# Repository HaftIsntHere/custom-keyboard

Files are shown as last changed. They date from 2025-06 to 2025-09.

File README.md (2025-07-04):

# Custom Keyboard
This is my fully custom keyboard, fitted with a 75% layout, 2 macro keys, a knob and an oled screen!

I made this project as a continuation for the hackpad, and I really wanted to know how building a real keyboard is, not just a macropad. This helped me finally understand how keyboards really work!
 <br>


## BOM

|Item |Quantity  |Price |Link # |
|---|---|---|---|
|INDIVIDUAL ITEMS | | | |
| | | | |
|Womier Coffee Cat keycaps |1 |26.54 USD |https://womierkeyboard.com/products/womier-coffee-cat-143?variant=40539585740871|
|Akko V3 Creamy Purple Pro switches |90 |33.72 USD |https://en.akkogear.com/product/akko-v3-creamy-purple-pro-switch |
|PCB |5 |13 + ~15 = 28 USD (can't see shipping estimate right now, it doesnt let me cause of war)| |
| | | | |
|ALIEXPRESS ITEMS | | | |
| | | | |
|Knob |1 |3.58 USD |https://www.aliexpress.com/item/1005007576522714.html |
|OLED Screen 128x32 |1 |3.68 USD |https://www.aliexpress.com/item/1005007038294972.html |
|DO-35 Diodes |100 |1.65 USD |https://www.aliexpress.com/item/4000142272546.html |
|Hot swap sockets |110 |15.59 USD |https://www.aliexpress.com/item/1005007476614771.html |
|Stabilizers (4x 2u + 1x 6.25u) |4+1 |7.24 USD |https://www.aliexpress.com/item/1005006528731543.html |
|ESP32 S3 Devkit C1 |1 |19.56 USD (including shipping) |https://www.aliexpress.com/item/1005003979778978.html |
|EC11 Rotary Encoder |1 |1.56 USD (including shipping) |https://www.aliexpress.com/item/1975155185.html |
|M3 Screws |20 |2.54 USD |https://www.aliexpress.com/item/32810872544.html |
|Poron strips |64 |4.75 USD |https://www.aliexpress.com/item/1005003607093794.html |
| | | | |
|AliExpress Total (including their discounts and stuff)| 51.33 USD| | |
| | | | |
|TOTAL | |139.59 USD | |

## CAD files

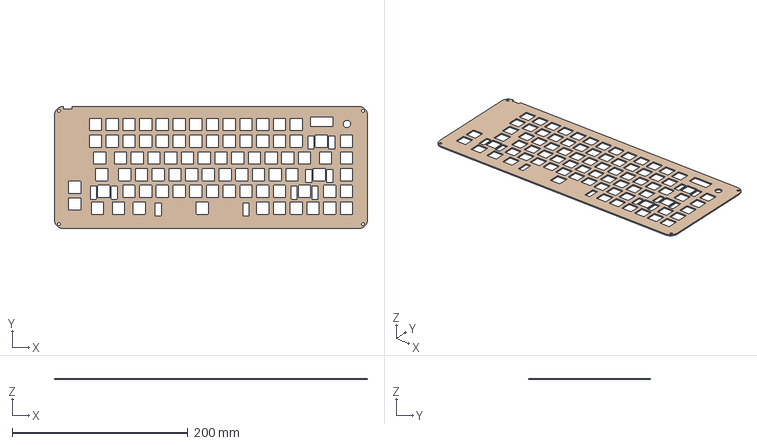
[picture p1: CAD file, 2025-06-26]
CAD/Top.step
356.4 x 139.1 x 1.50 mm

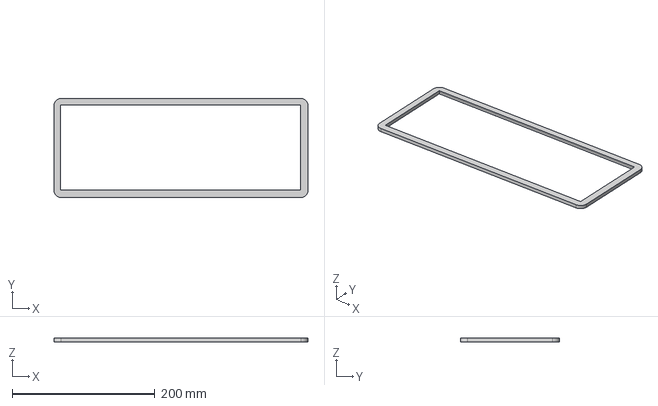
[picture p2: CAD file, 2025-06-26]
CAD/Top frame.step
356.5 x 139.0 x 5.00 mm

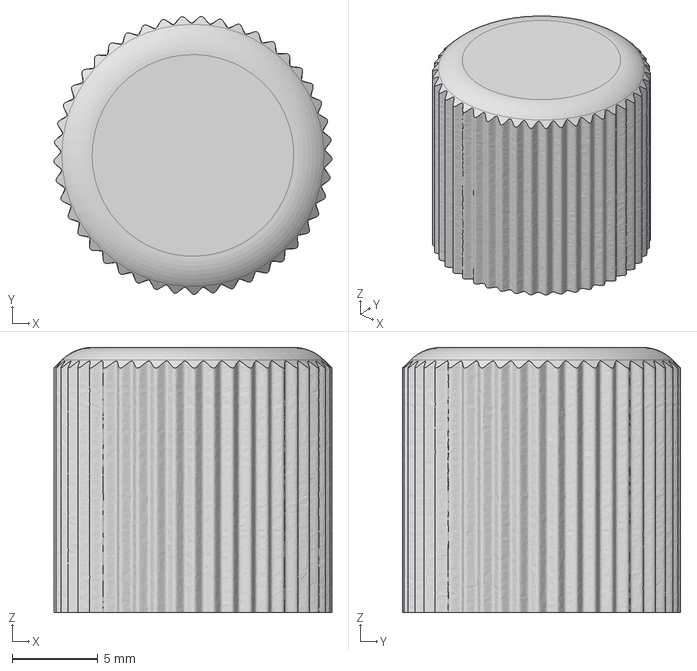
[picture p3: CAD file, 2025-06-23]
CAD/knob.step
16.3 x 16.2 x 15.5 mm

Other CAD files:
production/Bottom.step
CAD/Bottom.step
production/Knob cover.step

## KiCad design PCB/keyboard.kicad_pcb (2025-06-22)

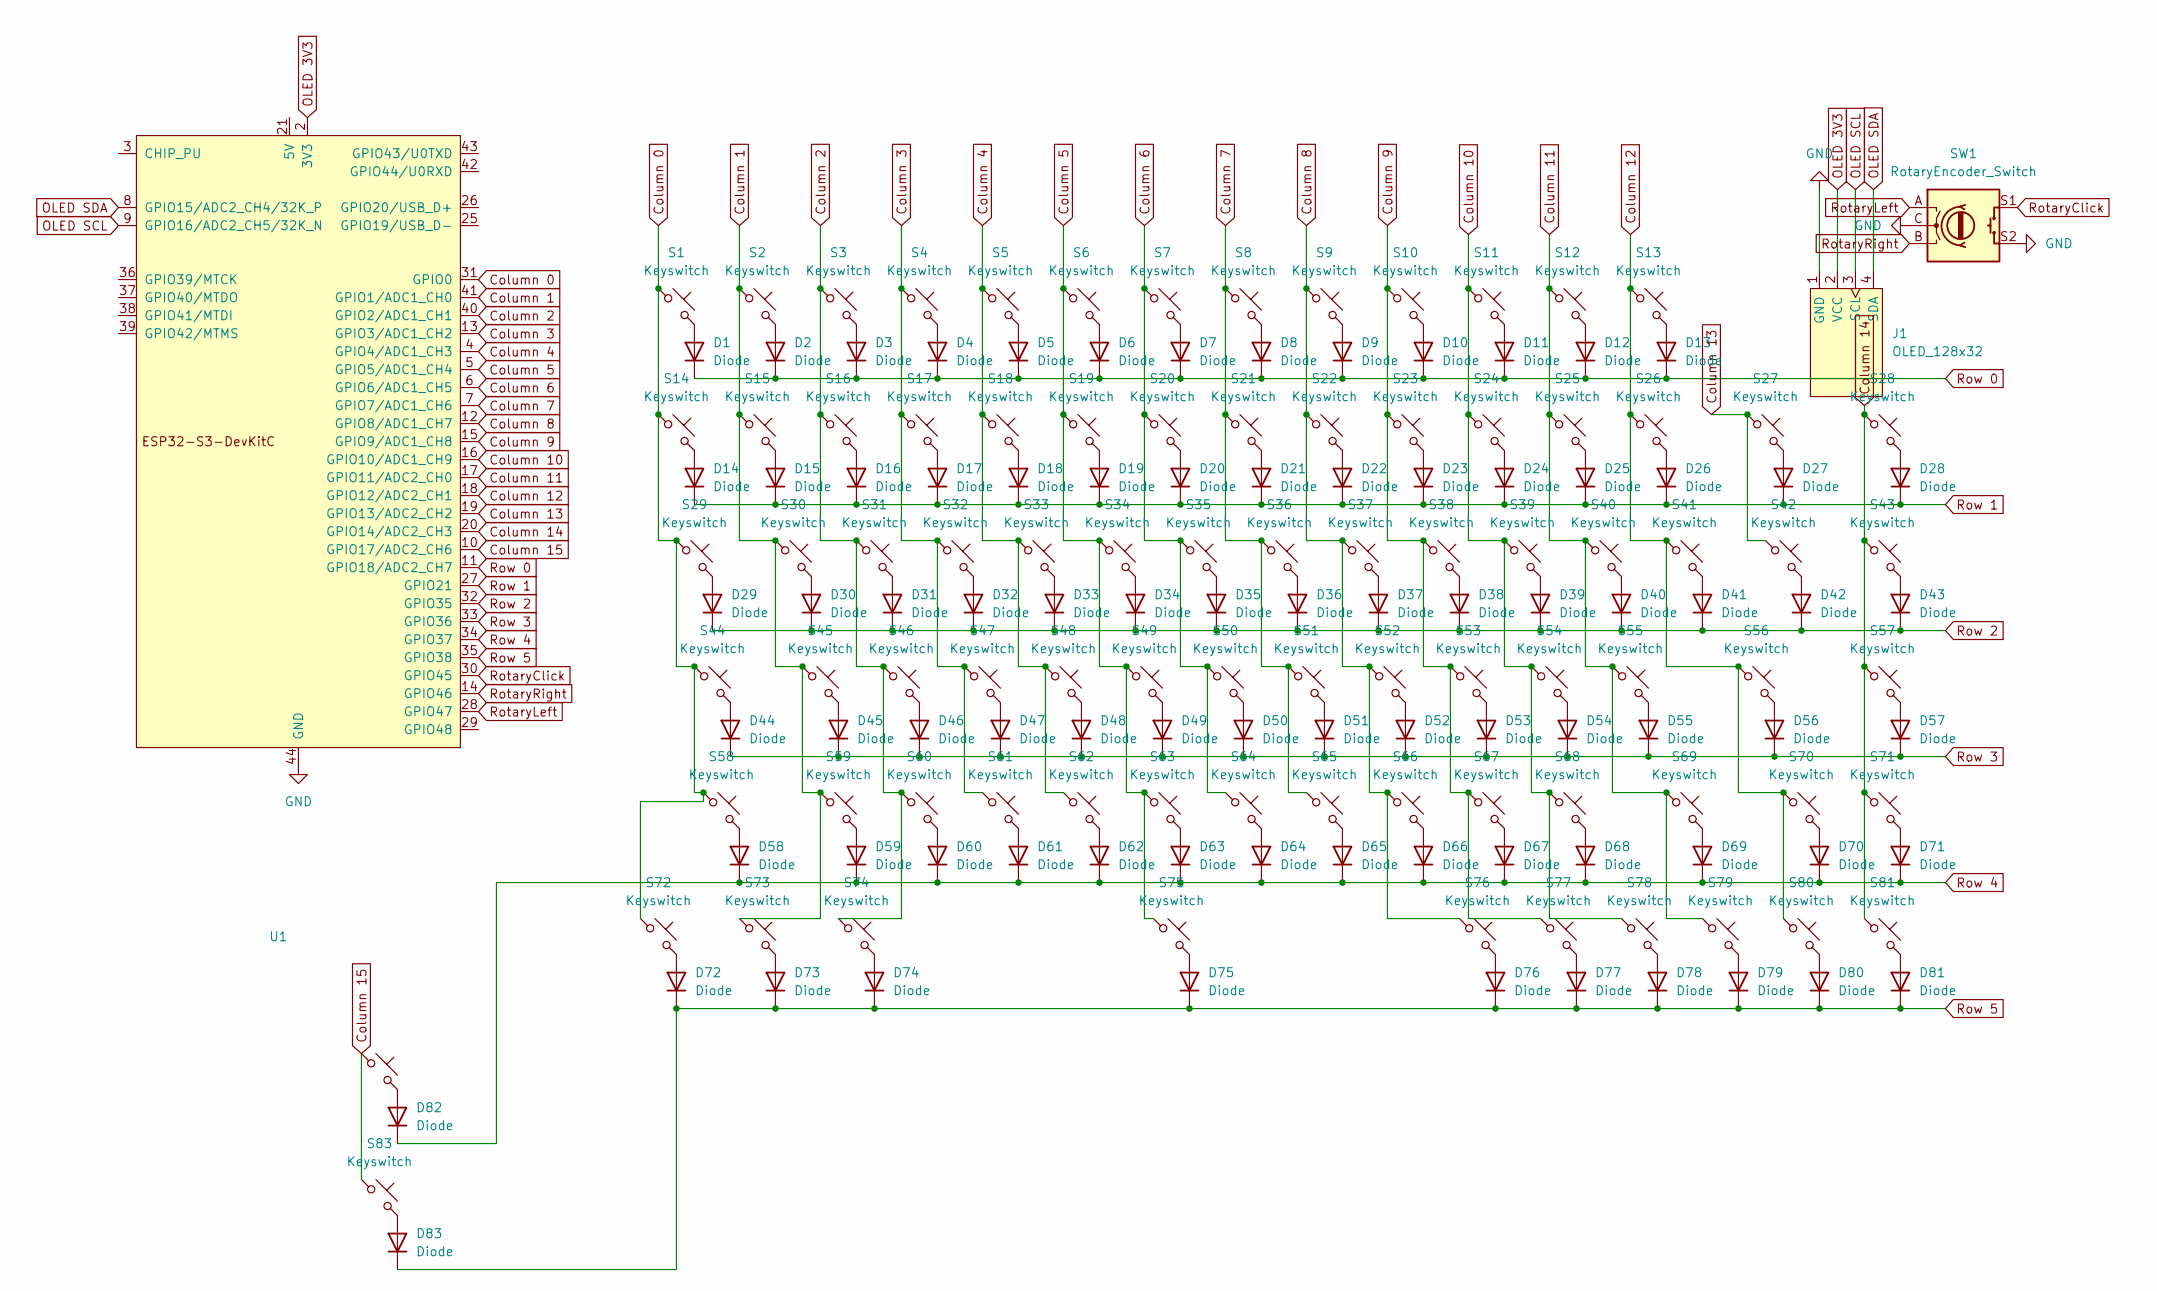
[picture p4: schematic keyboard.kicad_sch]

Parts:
D1, D2, D3, D4, D5, D6, D7, D8, D9, D10, D11, D12, D13, D14, D15, D16, D17, D18, D19, D20, D21, D22, D23, D24, D25, D26, D27, D28, D29, D30, D31, D32, D33, D34, D35, D36, D37, D38, D39, D40, D41, D42, D43, D44, D45, D46, D47, D48, D49, D50, D51, D52, D53, D54, D55, D56, D57, D58, D59, D60, D61, D62, D63, D64, D65, D66, D67, D68, D69, D70, D71, D72, D73, D74, D75, D76, D77, D78, D79, D80, D81, D82, D83: Diode; Diode_DO-35
J1: OLED_128x32
S1, S2, S3, S4, S5, S6, S7, S8, S9, S10, S11, S12, S13, S14, S15, S16, S17, S18, S19, S20, S21, S22, S23, S24, S25, S26, S28, S30, S31, S32, S33, S34, S35, S36, S37, S38, S39, S40, S41, S43, S45, S46, S47, S48, S49, S50, S51, S52, S53, S54, S55, S57, S59, S60, S61, S62, S63, S64, S65, S66, S67, S68, S70, S71, S76, S77, S78, S79, S80, S81, S82, S83: Keyswitch; Hotswap_MX_1.00u
S27, S58, S69: Keyswitch; Hotswap_MX_2.00u
S29, S42: Keyswitch; Hotswap_MX_1.50u
S44: Keyswitch; Hotswap_MX_1.75u
S56: Keyswitch; Hotswap_MX_2.25u
S72, S73, S74: Keyswitch; Hotswap_MX_1.25u
S75: Keyswitch; Hotswap_MX_6.25u
SW1: RotaryEncoder_Switch; RotaryEncoder_Alps_EC11E-Switch_Vertical_H20mm
U1: ESP32-S3-DevKitC

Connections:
Column 0: S1.1, S14.1, S29.1, S44.1, S58.1, S72.1, U1.31 (GPIO0)
Column 1: S2.1, S15.1, S30.1, S45.1, S59.1, S73.1, U1.41 (GPIO1/ADC1_CH0)
Column 2: S3.1, S16.1, S31.1, S46.1, S60.1, S74.1, U1.40 (GPIO2/ADC1_CH1)
Column 3: S4.1, S17.1, S32.1, S47.1, S61.1, U1.13 (GPIO3/ADC1_CH2)
Column 4: S5.1, S18.1, S33.1, S48.1, S62.1, U1.4 (GPIO4/ADC1_CH3)
Column 5: S6.1, S19.1, S34.1, S49.1, S63.1, S75.1, U1.5 (GPIO5/ADC1_CH4)
Column 6: S7.1, S20.1, S35.1, S50.1, S64.1, U1.6 (GPIO6/ADC1_CH5)
Column 7: S8.1, S21.1, S36.1, S51.1, S65.1, U1.7 (GPIO7/ADC1_CH6)
Column 8: S9.1, S22.1, S37.1, S52.1, S66.1, S76.1, U1.12 (GPIO8/ADC1_CH7)
Column 9: S10.1, S23.1, S38.1, S53.1, S67.1, S77.1, U1.15 (GPIO9/ADC1_CH8)
Column 10: S11.1, S24.1, S39.1, S54.1, S68.1, S78.1, U1.16 (GPIO10/ADC1_CH9)
Column 11: S12.1, S25.1, S40.1, S55.1, S69.1, S79.1, U1.17 (GPIO11/ADC2_CH0)
Column 12: S13.1, S26.1, S41.1, S56.1, S70.1, S80.1, U1.18 (GPIO12/ADC2_CH1)
Column 13: S27.1, S42.1, U1.19 (GPIO13/ADC2_CH2)
Column 14: S28.1, S43.1, S57.1, S71.1, S81.1, U1.20 (GPIO14/ADC2_CH3)
Column 15: S82.1, S83.1, U1.10 (GPIO17/ADC2_CH6)
GND: J1.1 (GND), SW1.C, SW1.S2, U1.22 (GND), U1.23 (GND), U1.24 (GND), U1.44 (GND)
unnamed: D1.2 (A), S1.2
unnamed: D2.2 (A), S2.2
unnamed: D3.2 (A), S3.2
unnamed: D4.2 (A), S4.2
unnamed: D5.2 (A), S5.2
unnamed: D6.2 (A), S6.2
unnamed: D7.2 (A), S7.2
unnamed: D8.2 (A), S8.2
unnamed: D9.2 (A), S9.2
unnamed: D10.2 (A), S10.2
unnamed: D11.2 (A), S11.2
unnamed: D12.2 (A), S12.2
unnamed: D13.2 (A), S13.2
unnamed: D14.2 (A), S14.2
unnamed: D15.2 (A), S15.2
unnamed: D16.2 (A), S16.2
unnamed: D17.2 (A), S17.2
unnamed: D18.2 (A), S18.2
unnamed: D19.2 (A), S19.2
unnamed: D20.2 (A), S20.2
unnamed: D21.2 (A), S21.2
unnamed: D22.2 (A), S22.2
unnamed: D23.2 (A), S23.2
unnamed: D24.2 (A), S24.2
unnamed: D25.2 (A), S25.2
unnamed: D26.2 (A), S26.2
unnamed: D27.2 (A), S27.2
unnamed: D28.2 (A), S28.2
unnamed: D29.2 (A), S29.2
unnamed: D30.2 (A), S30.2
unnamed: D31.2 (A), S31.2
unnamed: D32.2 (A), S32.2
unnamed: D33.2 (A), S33.2
unnamed: D34.2 (A), S34.2
unnamed: D35.2 (A), S35.2
unnamed: D36.2 (A), S36.2
unnamed: D37.2 (A), S37.2
unnamed: D38.2 (A), S38.2
unnamed: D39.2 (A), S39.2
unnamed: D40.2 (A), S40.2
unnamed: D41.2 (A), S41.2
unnamed: D42.2 (A), S42.2
unnamed: D43.2 (A), S43.2
unnamed: D44.2 (A), S44.2
unnamed: D45.2 (A), S45.2
unnamed: D46.2 (A), S46.2
unnamed: D47.2 (A), S47.2
unnamed: D48.2 (A), S48.2
unnamed: D49.2 (A), S49.2
unnamed: D50.2 (A), S50.2
unnamed: D51.2 (A), S51.2
unnamed: D52.2 (A), S52.2
unnamed: D53.2 (A), S53.2
unnamed: D54.2 (A), S54.2
unnamed: D55.2 (A), S55.2
unnamed: D56.2 (A), S56.2
unnamed: D57.2 (A), S57.2
unnamed: D58.2 (A), S58.2
unnamed: D59.2 (A), S59.2
unnamed: D60.2 (A), S60.2
unnamed: D61.2 (A), S61.2
unnamed: D62.2 (A), S62.2
unnamed: D63.2 (A), S63.2
unnamed: D64.2 (A), S64.2
unnamed: D65.2 (A), S65.2
unnamed: D66.2 (A), S66.2
unnamed: D67.2 (A), S67.2
unnamed: D68.2 (A), S68.2
unnamed: D69.2 (A), S69.2
unnamed: D70.2 (A), S70.2
unnamed: D71.2 (A), S71.2
unnamed: D72.2 (A), S72.2
unnamed: D73.2 (A), S73.2
unnamed: D74.2 (A), S74.2
unnamed: D75.2 (A), S75.2
unnamed: D76.2 (A), S76.2
unnamed: D77.2 (A), S77.2
unnamed: D78.2 (A), S78.2
unnamed: D79.2 (A), S79.2
unnamed: D80.2 (A), S80.2
unnamed: D81.2 (A), S81.2
unnamed: D82.2 (A), S82.2
unnamed: D83.2 (A), S83.2
OLED 3V3: J1.2 (VCC), U1.1 (3V3), U1.2 (3V3)
OLED SCL: J1.3 (SCL), U1.9 (GPIO16/ADC2_CH5/32K_N)
OLED SDA: J1.4 (SDA), U1.8 (GPIO15/ADC2_CH4/32K_P)
RotaryClick: SW1.S1, U1.30 (GPIO45)
RotaryLeft: SW1.A, U1.28 (GPIO47)
RotaryRight: SW1.B, U1.14 (GPIO46)
Row 0: D1.1 (K), D2.1 (K), D3.1 (K), D4.1 (K), D5.1 (K), D6.1 (K), D7.1 (K), D8.1 (K), D9.1 (K), D10.1 (K), D11.1 (K), D12.1 (K), D13.1 (K), U1.11 (GPIO18/ADC2_CH7)
Row 1: D14.1 (K), D15.1 (K), D16.1 (K), D17.1 (K), D18.1 (K), D19.1 (K), D20.1 (K), D21.1 (K), D22.1 (K), D23.1 (K), D24.1 (K), D25.1 (K), D26.1 (K), D27.1 (K), D28.1 (K), U1.27 (GPIO21)
Row 2: D29.1 (K), D30.1 (K), D31.1 (K), D32.1 (K), D33.1 (K), D34.1 (K), D35.1 (K), D36.1 (K), D37.1 (K), D38.1 (K), D39.1 (K), D40.1 (K), D41.1 (K), D42.1 (K), D43.1 (K), U1.32 (GPIO35)
Row 3: D44.1 (K), D45.1 (K), D46.1 (K), D47.1 (K), D48.1 (K), D49.1 (K), D50.1 (K), D51.1 (K), D52.1 (K), D53.1 (K), D54.1 (K), D55.1 (K), D56.1 (K), D57.1 (K), U1.33 (GPIO36)
Row 4: D58.1 (K), D59.1 (K), D60.1 (K), D61.1 (K), D62.1 (K), D63.1 (K), D64.1 (K), D65.1 (K), D66.1 (K), D67.1 (K), D68.1 (K), D69.1 (K), D70.1 (K), D71.1 (K), D82.1 (K), U1.34 (GPIO37)
Row 5: D72.1 (K), D73.1 (K), D74.1 (K), D75.1 (K), D76.1 (K), D77.1 (K), D78.1 (K), D79.1 (K), D80.1 (K), D81.1 (K), D83.1 (K), U1.35 (GPIO38)

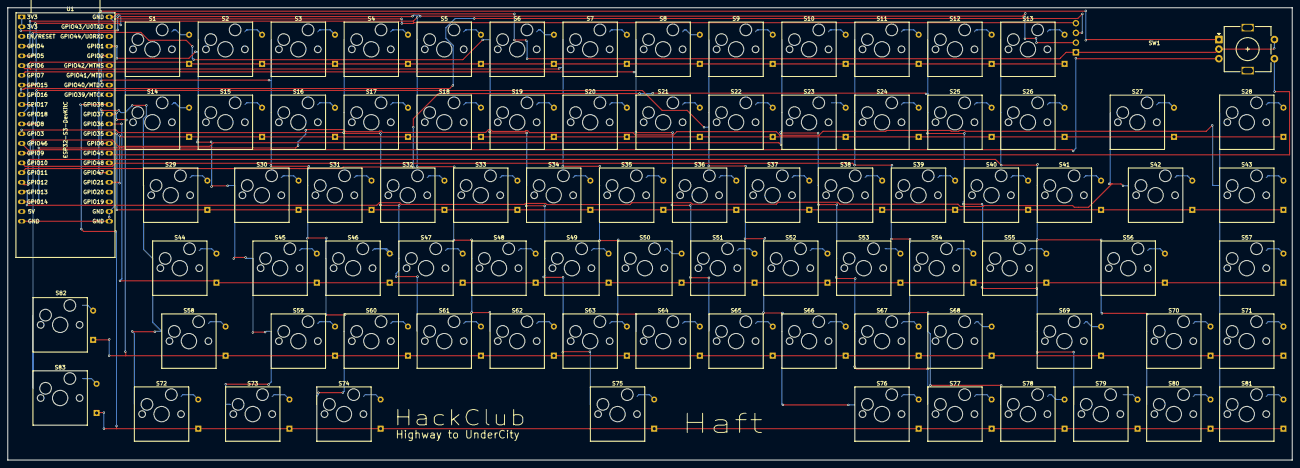
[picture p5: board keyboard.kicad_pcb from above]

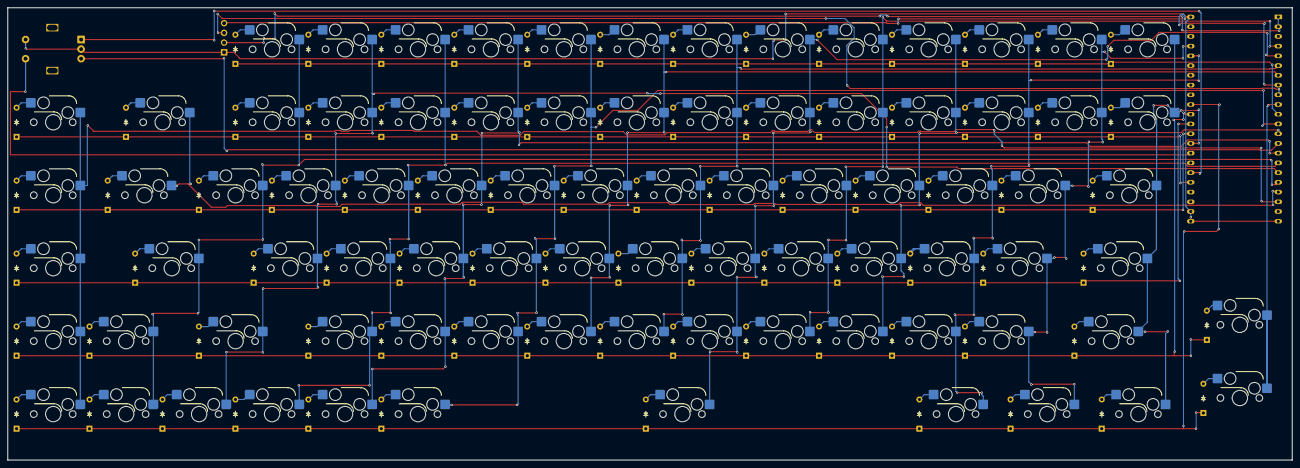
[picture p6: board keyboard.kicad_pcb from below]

Board: 2 copper layers, 335.4 x 118.1 mm, 169 parts (83 on the bottom side), 112 nets.

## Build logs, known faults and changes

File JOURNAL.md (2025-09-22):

---
title: "My Custom Keyboard"
author: "Haft"
description: "My very own custom keyboard, with its own PCB!"
created_at: "2025-06-20"
---

### **Total time working:** 20 hours, 11 minutes

> On hackatime the Fusion360 shows as <<LAST_PROJECT>>, the KiCAD shows as keyboard, and the KMK firmware shows as firmware

# June 20th, 2025

I have used this tutorial to make the PCB (of course, in an actual keyboard size and not just a 3x3 <br>
PCB Design Tutorial (https://youtu.be/8WXpGTIbxlQ)
### Schematic:
 <br>
### PCB Result:
 <br>
 <br>
A fully featured keyboard PCB for a 75% keyboard, with an oled screen and a knob. Tomorrow I expect a long day as I will be designing the 3D case for it. 
I have made multiple mistakes, like messing up the order of the switches, which took me 30 minutes to fix, accidentally connecting the screen to 3V3_EN instead of 3V3 and more.
**Total time today:** 3 hours, 11 minutes

# June 21st, 2025
I have updated unrouted lines that I missed in the PCB, and fixed a few more issues.
I also moved the OLED screen to the center, and replaced the main board from Pi Pico to ESP S3 Devkit C (took me 2 more hours).
The new schematic and PCB look like this:

 <br>
I also added 3 macro keys, and because I moved things around everything looks slimmer and better!
I had to reroute everything twice, and I recommend you guys to follow this rule: **Back for vertical, front for horizontal (or vise-varsa)**
I really recommend you check your PCB multiple times before making the case, it was really tedious to redo it after editing the PCB today (I first started with case, and only then made the PCB changes so I had to redo case)
Current case state:
 <br>
I took about 2 hours for the case itself. And it's not done yet (need coloring, cutouts and a few more refinements)
**Total time today:** 5.5 hours 

# June 22nd, 2025
I changed the PCB once again, this time making it even slimmer and not bulky

 <br>

I'm very annoying at this point because I already changed the PCB three times and every time I have to redo the case, but, I mean, who am I to blame? The case looked bulky AF because of the PCB: <br>  <br>
This time, I'm going to make sure everything is slimmer so the keyboard doesnt look so bulky!
Finally done with that case! You should measure 3 times before making, I messed up my measurements multiple times, but now they're perfect!
Without switches & keycaps: <br> 
 <br>
With switches & keycaps: <br>  
 <br>

 Now that the keyboard itself is done, all that's left is the software! Will do that tomorrow!!
 **Total time today:** 8.5 hours

 # June 23rd, 2025
There wasn't much to do today. Almost everything was done and all I did was the sofware. Iran woke me up 3 hours ago (10 am) because of their missiles, and I just finished the KMK firmware.
It was very simple and easy, I just followed the tutorial and in no time I was done!
There isn't any picture to show today, because it was just firmware. Check it out at firmware/main.py!

I also chose a new color pallete for the keyboard


**Total time today:** 1 hour

# June 26th, 2025
My keyboard just got rejected!
And to be honest, I'm glad. The reviewer said I should look into different mounting styles, and I found out that just have 4 screw in the top isn't very..... smart lol
I decided to use the gasket mount! Which whilst may be a little more expensive than the others, it offers exceptional sound in return and isn't that hard to install!
I went with these poron foams for the gasket https://www.aliexpress.com/item/1005003607093794.html <br>


**Total time today:** 2 hours

This mount is way better in basically any way, and makes the keyboard look better, sound better, and feel better!
I also added hackclub branding!


# July 30th, 2025
My keyboard (finally) was accepted! 
I have ordered the keycaps and switches, but the PCB is too expensive to buy right now (gotta wait for shipping prices to go back down), and AliExpress banned my HCB card for some reason so I'm waiting to get a new one for that.

# September 17th, 2025
All my parts arrived today, after a 1.5 months of waiting and highway ending.<br>
6EBC56DD-3694-4132-B35A-50FF13282107_1_105_c <br>
I have also started work on it today, and I will try to finish it over the weekend.
I got the diodes set up on the PCB, and that took me about an hour
**Total time today:** 1 hour

# September 22nd, 2025
With the help of my dad (who majored in electronics and was soldering a lot in his youth), I have finished soldering all the diodes and sockets!
This took us 3 hours of work. But the end result looks AMAZING from the front!

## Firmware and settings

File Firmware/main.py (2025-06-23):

import time
import board
import busio
from kmk.kmk.kmk_keyboard import KMKKeyboard
from kmk.kmk.scanners import DiodeOrientation
from kmk.kmk.keys import KC
from kmk.kmk.modules.encoder import EncoderHandler
from kmk.kmk.extensions.display.ssd1306 import SSD1306
from kmk.kmk.extensions.display import Display, TextEntry

keyboard = KMKKeyboard()

i2c_bus = busio.I2C(board.IO16, board.IO15)

driver = SSD1306(
    width=128,
    height=32,
    i2c=i2c_bus,
)

display = Display(
    display=driver,
    width=128,
    height=32,
    brightness=1.0,
    brighness_step=0.1,
)

display.entries = [TextEntry(display, "Welcome!", x=0, y=0)]
keyboard.extensions.append(display)

keyboard.row_pins = (
    board.IO18,
    board.IO21,
    board.IO35,
    board.IO36,
    board.IO37,
    board.IO38,
)

keyboard.col_pins = (
    board.IO0,
    board.IO1,
    board.IO2,
    board.IO3,
    board.IO4,
    board.IO5,
    board.IO6,
    board.IO7,
    board.IO8,
    board.IO9,
    board.IO10,
    board.IO11,
    board.IO12,
    board.IO13,
    board.IO14,
    board.IO17,
)

keyboard.diode_orientation = DiodeOrientation.COL2ROW

keyboard.keymap = [
    [
        KC.ESC,
        KC.F1,
        KC.F2,
        KC.F3,
        KC.F4,
        KC.F5,
        KC.F6,
        KC.F7,
        KC.F8,
        KC.F9,
        KC.F10,
        KC.F11,
        KC.F12,
        KC.NO,
        KC.N0,
        KC.N0,
    ],
    [
        KC.GRAVE,
        KC._1,
        KC._2,
        KC._3,
        KC._4,
        KC._5,
        KC._6,
        KC._7,
        KC._8,
        KC._9,
        KC._0,
        KC.MINS,
        KC.EQL,
        KC.BSPC,
        KC.PGUP,
        KC.N0,
    ],
    [
        KC.TAB,
        KC.Q,
        KC.W,
        KC.E,
        KC.R,
        KC.T,
        KC.Y,
        KC.U,
        KC.I,
        KC.O,
        KC.P,
        KC.LBRC,
        KC.RBRC,
        KC.BSLS,
        KC.PGDN,
        KC.N0,
    ],
    [
        KC.CAPS,
        KC.A,
        KC.S,
        KC.D,
        KC.F,
        KC.G,
        KC.H,
        KC.J,
        KC.K,
        KC.L,
        KC.SCLN,
        KC.QUOT,
        KC.ENT,
        KC.NO,
        KC.HOME,
        KC.N0,
    ],
    [
        KC.LSFT,
        KC.Z,
        KC.X,
        KC.C,
        KC.V,
        KC.B,
        KC.N,
        KC.M,
        KC.COMM,
        KC.DOT,
        KC.SLSH,
        KC.RSFT,
        KC.UP,
        KC.N0,
        KC.END,
        KC.F13,
    ],
    [
        KC.LCTL,
        KC.LALT,
        KC.LGUI,
        KC.N0,
        KC.N0,
        KC.SPC,
        KC.N0,
        KC.N0,
        KC.RGUI,
        KC.FN0,
        KC.RCTL,
        KC.LEFT,
        KC.DOWN,
        KC.N0,
        KC.RIGHT,
        KC.F14,
    ],
]


encoder_handler = EncoderHandler()
keyboard.modules.append(encoder_handler)

encoder_handler.pins = ((board.IO47, board.IO46, board.IO45),)

encoder_handler.map = [((KC.VOLD, KC.VOLU, KC.MUTE))]


print("Keyboard online!")

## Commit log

2025-06-20 Add PCB files from KiCAD
    [keyboard.kicad_pcb, keyboard.kicad_sch]
2025-06-20 add production files and gerbers generated
    [bom.csv, designators.csv, positions.csv]
2025-06-22 update gerbers
    [bom.csv]
2025-06-22 Add kicad files
    [keyboard.kicad_pcb, keyboard.kicad_sch]
2025-06-23 Update and rename production/bom.csv to bom.csv
    [bom.csv]
2025-06-23 Move BOM and make it more readable
    [bom.csv]
2025-06-23 Create CAD
2025-06-23 add CAD
    [Bottom.step, Knob cover.step, Top.step]
2025-06-23 update keyboard with new color
    [Bottom.step, Top.step, knob.step]
2025-06-23 add stabilizers to bom
    [bom.csv]
2025-07-04 fix full assembly pic
